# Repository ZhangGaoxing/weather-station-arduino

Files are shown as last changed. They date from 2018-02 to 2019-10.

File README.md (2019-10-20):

# Weather Station
## Introduction
This project includes an Arduino-based weather station, an ASP.NET Core MVC data presentation page, and an ASP.NET Core WebAPI. The collected data is sent using ESP8266 and written to the SQL Server database via WebAPI. The weather station consists of the following parts:

* Arduino Nano
* Nano Shield
* BME280 - Temperature, Humidity & Pressure Sensor
* ~~AM2320 - Digital Temperature and Humidity Sensor~~
* ~~BMP280 - Barometric Pressure and Altitude Sensor~~
* ~~ML8511 - UV sensor (Abandon)~~
* GP2Y1010F45 - Optical Dust Sensor
* DS3231 - RTC
* ESP8266 - WIFI
* SD card module
* 18650 Li-ion and Charger (Optional)

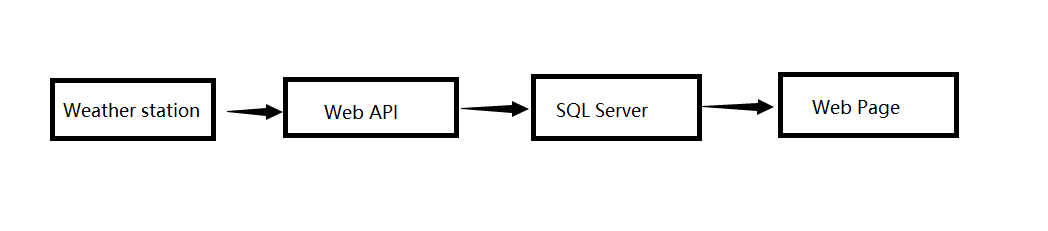
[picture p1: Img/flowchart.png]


Most of the referenced libraries come from Adafruit and Aduino Playground, and some I don't know who written it. AM2320 comes from [thakshak](https://github.com/thakshak/AM2320).

## Components
||Name|Count|
|---|:---|---:|
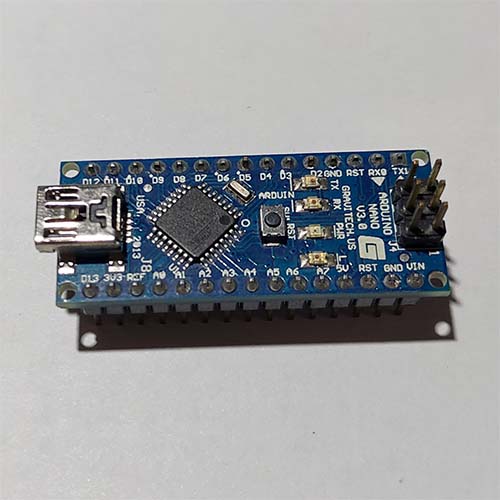
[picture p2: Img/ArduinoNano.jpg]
||Arduino Nano|x1|
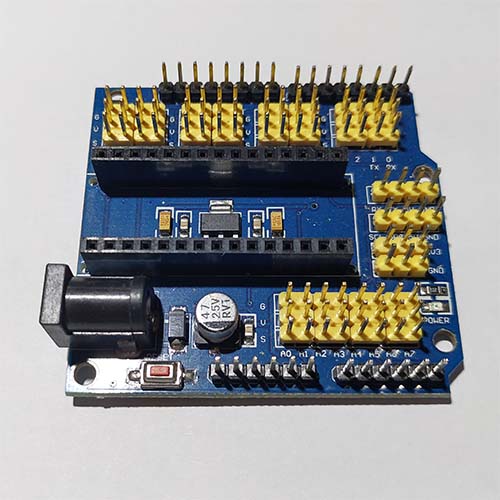
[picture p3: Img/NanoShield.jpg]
||Nano Shield|x1|
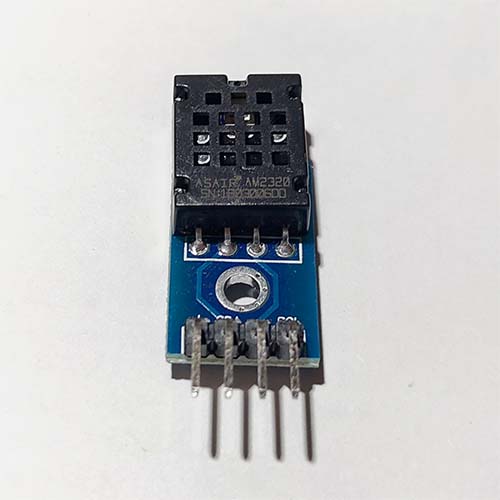
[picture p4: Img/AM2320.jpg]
||AM2320|x1|
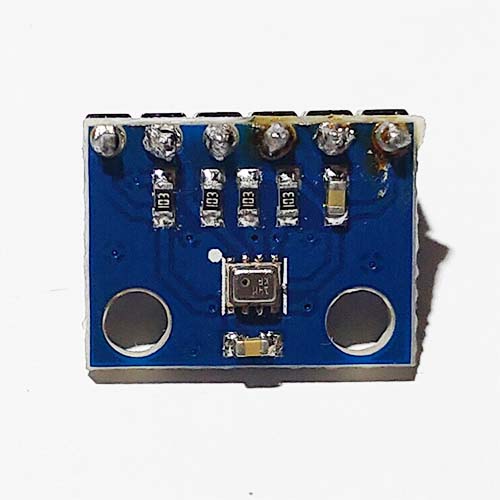
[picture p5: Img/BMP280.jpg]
||BMP280|x1|
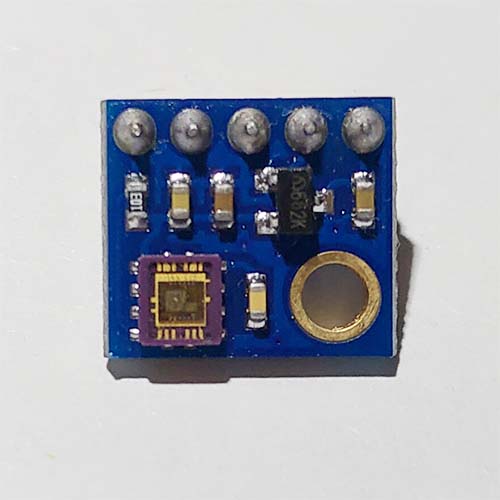
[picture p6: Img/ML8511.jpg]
||ML8511|x1|
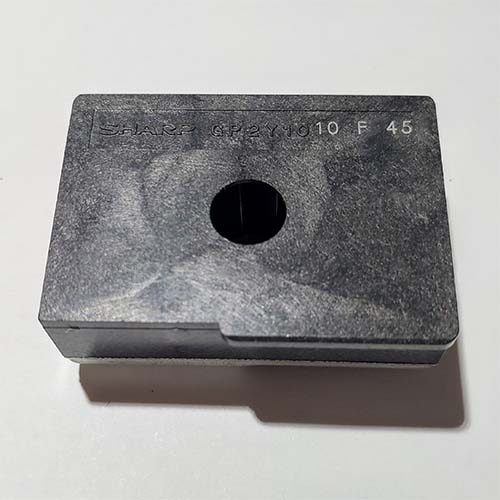
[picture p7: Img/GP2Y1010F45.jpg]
||GP2Y1010F45|x1|
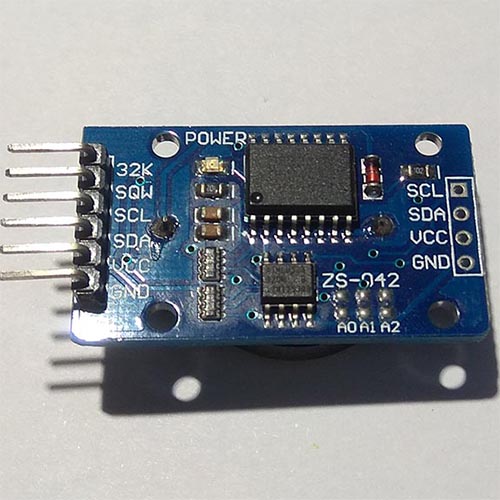
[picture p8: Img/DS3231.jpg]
||DS3231|x1|
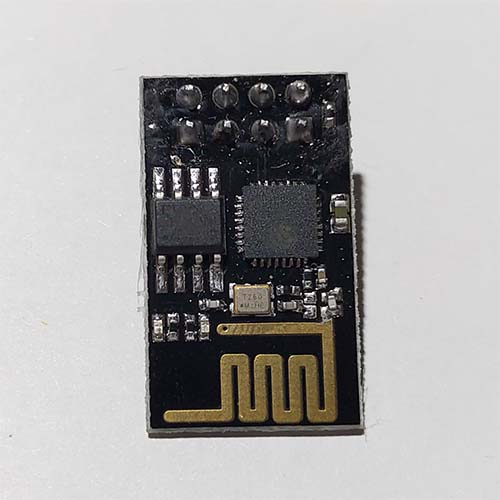
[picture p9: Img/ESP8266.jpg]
||ESP8266|x1|
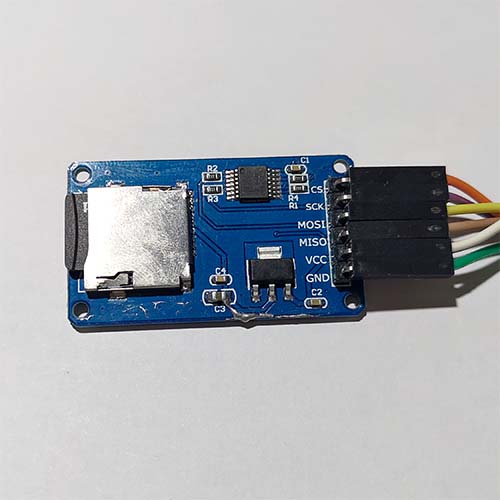
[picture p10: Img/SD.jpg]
||SD card module|x1|
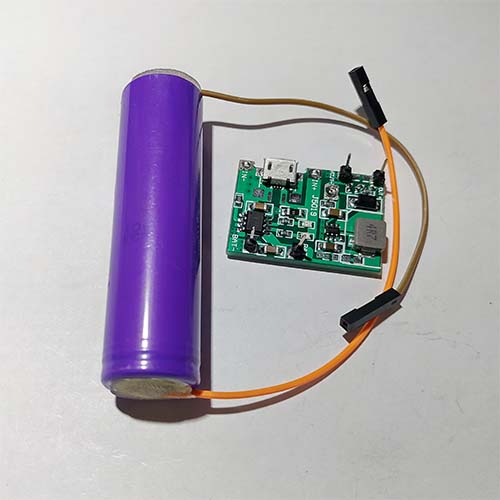
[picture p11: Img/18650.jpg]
||18650 Li-ion and Charger (Optional)|x1|
||Male/Female Jumper Wires|some|

## Apps
||Name|
|---|---|
||Arduino IDE|
||Microsoft Visual Studio 2017|
||Microsoft SQL Server|

## Arduino Connection
* I2C Sensors
  * VCC - 5V
  * GND - GND
  * SDA - A4
  * SCL - A5
  
* ML8511
  * VIN - 3.3V
  * OUT - A0
  * GND - GND
  * EN - 3.3V
  * 3.3V - A1

* GP2Y1010F45
  * Sharp pin 1 (V-LED) - 5V (Series 150Ω resistor, pin 1 and resistance connected to 220 μF capacitor and grounded)
  * Sharp pin 2 (LED-GND) - GND
  * Sharp pin 3 (LED) - pin 4
  * Sharp pin 4 (S-GND) - GND
  * Sharp pin 5 (Vo) - A2
  * Sharp pin 6 (Vcc) - 5V

* ESP8266
  * TX - pin 3
  * RX - pin 2
  * CH_PD - pin 5
  * VCC - 3.3V
  * GND - GND

* SD Card
  * MOSI - pin 11
  * MISO - pin 12
  * CLK - pin 13
  * CS - pin 10

## How to Use
Connect sensors to Arduino.

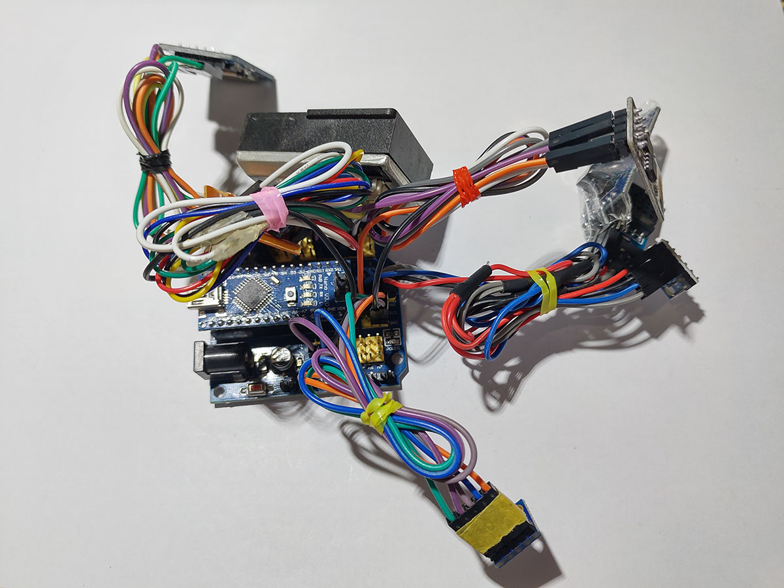
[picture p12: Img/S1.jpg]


### In ASP.NET Core
1. Open "**WeatherStation.sln**" and rebuild solution
   
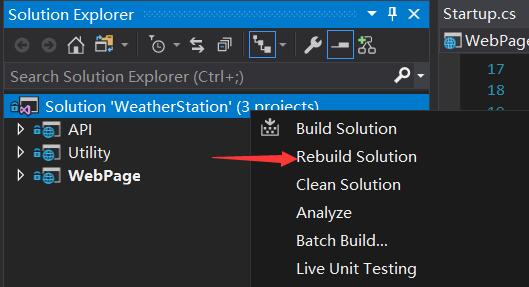
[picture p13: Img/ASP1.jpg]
    

2. In project **Utility**, open **WeatherContext.cs**, change connection string

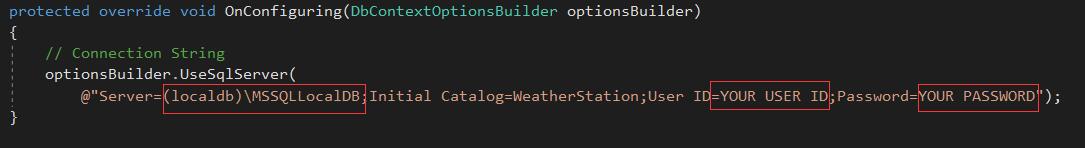
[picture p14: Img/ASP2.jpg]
    

3. In project **API**, open Controllers - **WeatherController.cs**, change token

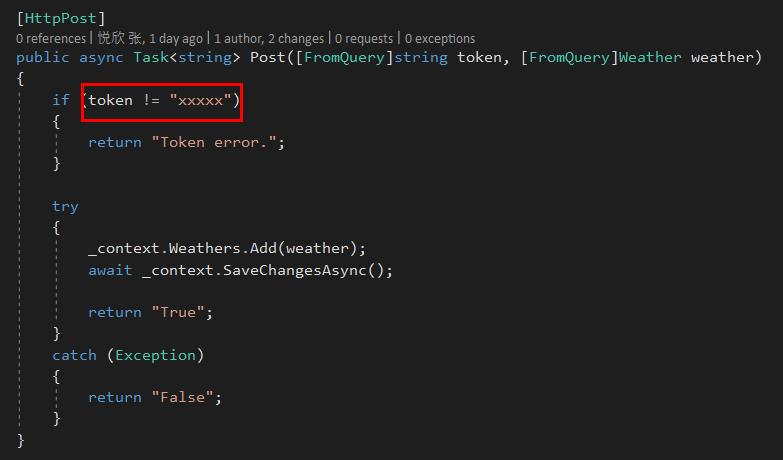
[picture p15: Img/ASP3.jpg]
    

4. Open Tools - NuGet Package Manager - **Package Manager Console**, change **Default project** to **Utility**
   
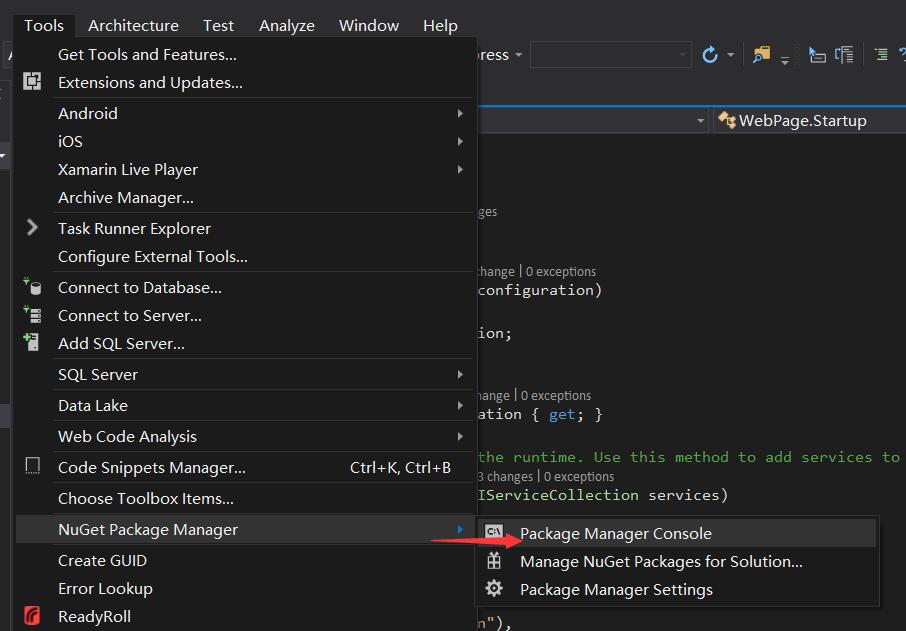
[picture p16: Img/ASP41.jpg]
    
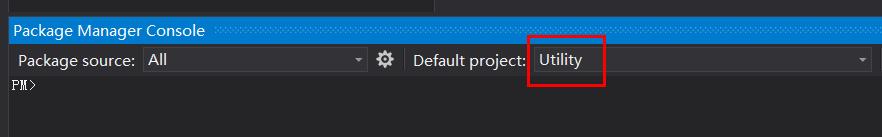
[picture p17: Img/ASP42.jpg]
    

    in PMC run this
    ```
    PM> Add-Migration Initial
    PM> Update-Database
    ```
    or run this SQL (PostgreSQL script)
    ```SQL
    create database "WeatherStation";

    create table weather (
        weather_id           SERIAL not null,
        date_time            TIMESTAMP            null,
        weather_name         VARCHAR(10)          null,
        temperature          NUMERIC(4,2)         null,
        humidity             NUMERIC(4,2)         null,
        pressure             NUMERIC(10,2)        null,
        dust                 NUMERIC(4)           null,
        uv                   DECIMAL(4,2)         null,
        constraint PK_WEATHER primary key (weather_id)
    );

    insert into "public"."weather" ("weather_id","date_time","weather_name","temperature","humidity","pressure","dust","uv") VALUES (1, '2019-01-01 21:00:00', NULL, -0.90, 25.80, 103662.72, 0, 0.01),(2, '2019-01-01 22:00:00', NULL, -1.50, 28.80, 103729.69, 0, 0.01),(3, '2019-01-01 23:00:00', NULL, -2.20, 29.60, 103632.05, 0, 0.01),(4, '2019-01-02 00:00:00', NULL, -2.90, 31.80, 103884.52, 0, 0.01),(5, '2019-01-02 01:00:00', NULL, -3.60, 33.80, 103603.38, 0, 0.01),(6, '2019-01-02 02:00:00', NULL, -3.50, 32.80, 103704.99, 0, 0.01),(7, '2019-01-02 03:00:00', NULL, -3.10, 31.20, 103872.41, 0, 0.01),(8, '2019-01-02 04:00:00', NULL, -2.70, 29.20, 103882.69, 0, 0.01);
    ```

5. Publish **API**, **WebPage** to your server

### In Arduino
1. Copy libraries to **x:\Program Files (x86)\Arduino\libraries**
2. Open "**WeatherStation.ino**"
3. In **Line 134**, replace your WIFI name and password
4. In **Line 139**, replace your server address and port
5. In **Line 150**, replace your Token
6. In **Line 155**, replace your Host

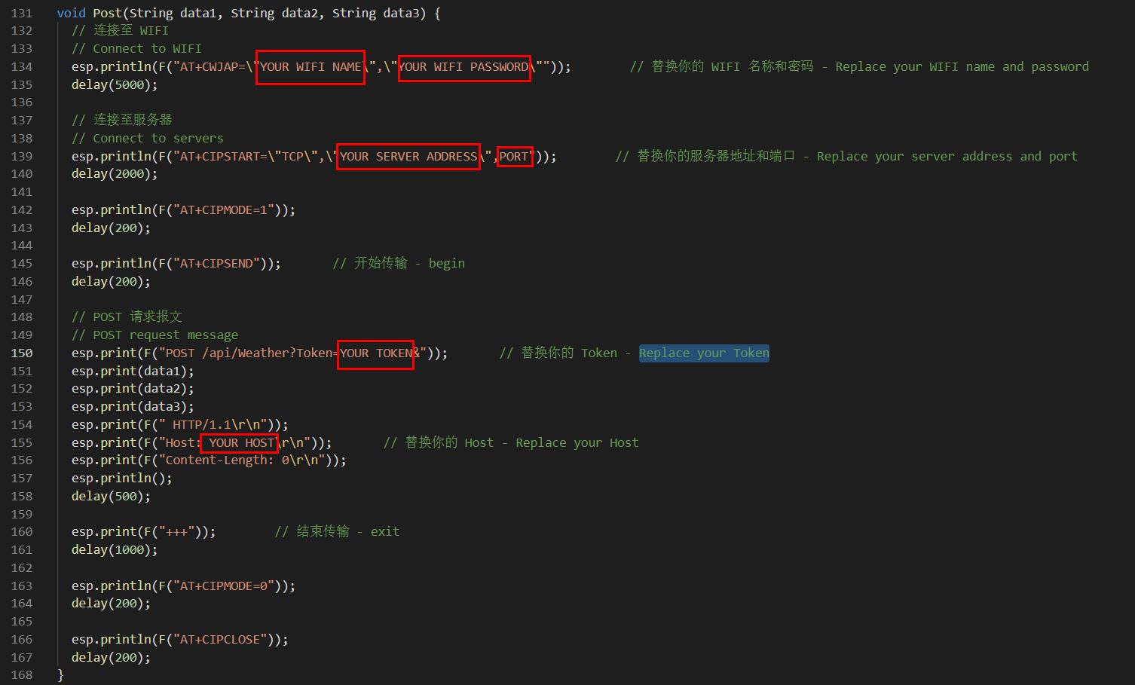
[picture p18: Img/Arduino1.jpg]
    

7. Upload program to your Arduino

## Demo Page
[http://weatherstation.zhangyue.xin/](http://weatherstation.zhangyue.xin)

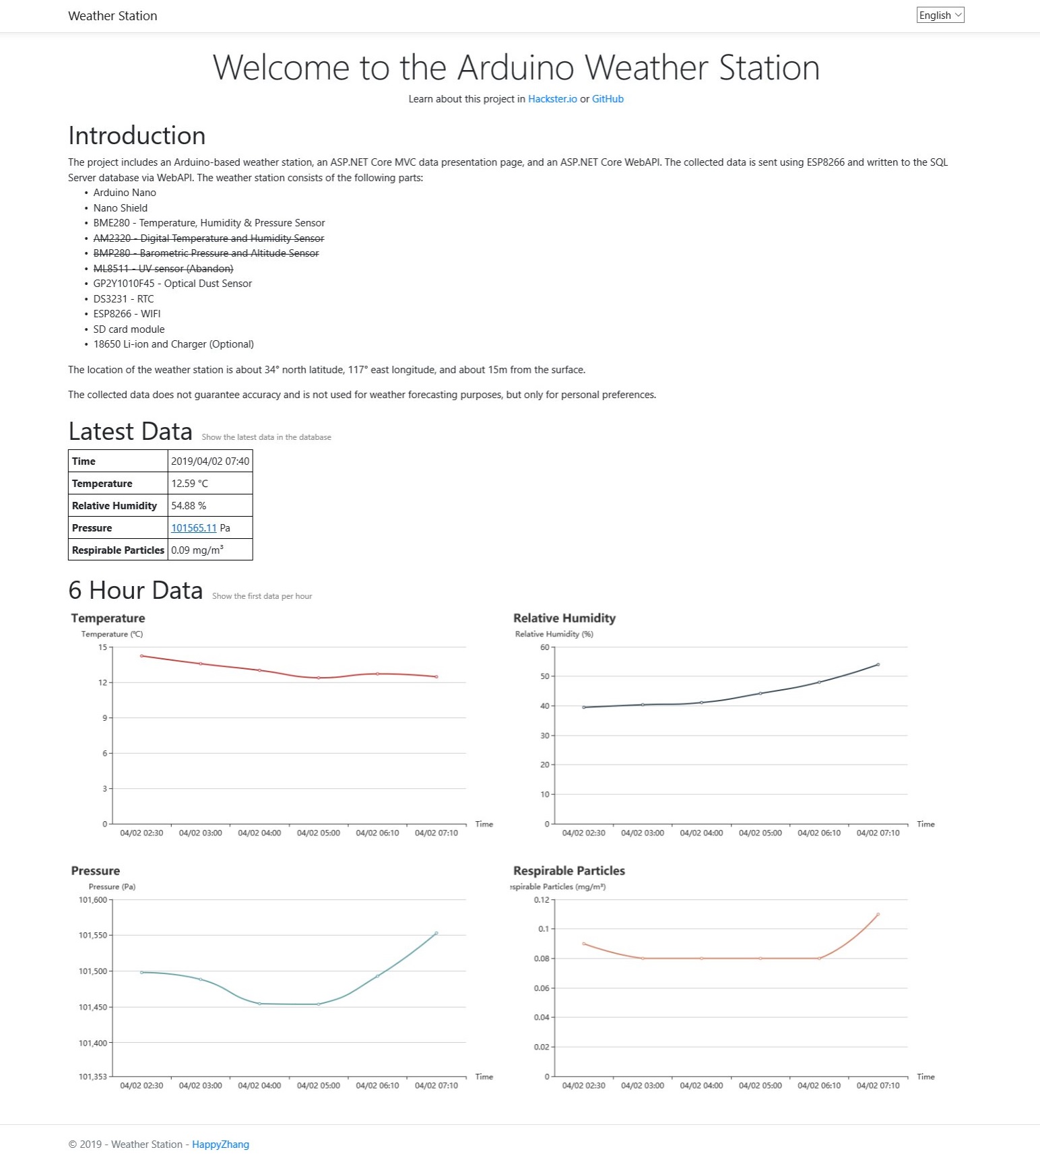
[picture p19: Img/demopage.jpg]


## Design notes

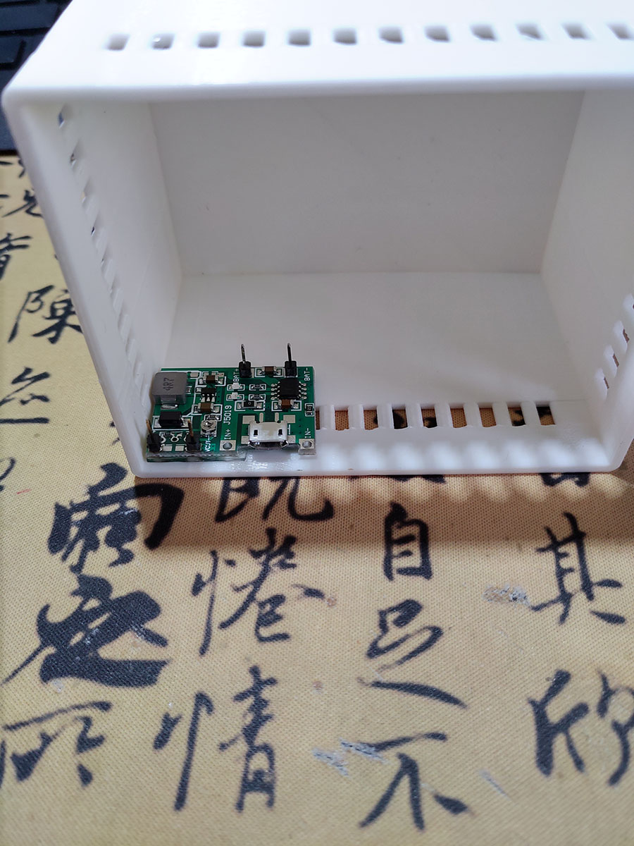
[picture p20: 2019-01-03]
Img/S2.jpg

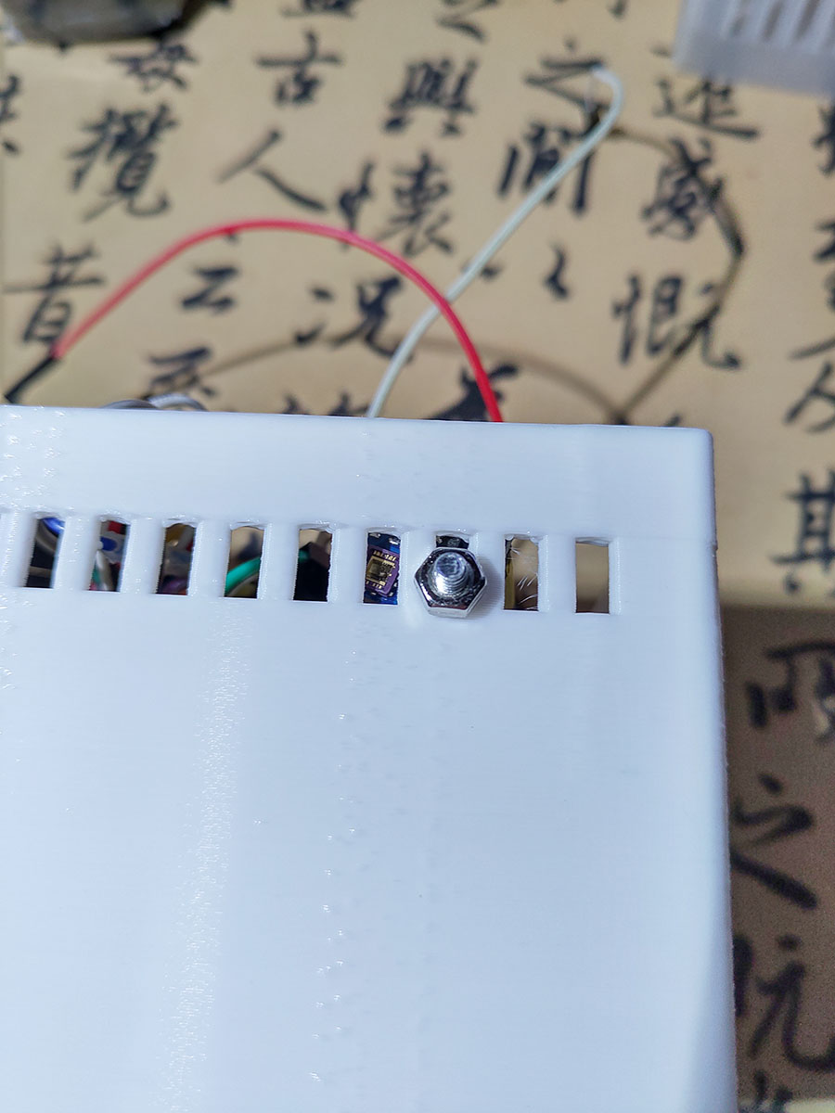
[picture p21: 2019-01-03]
Img/S4.jpg

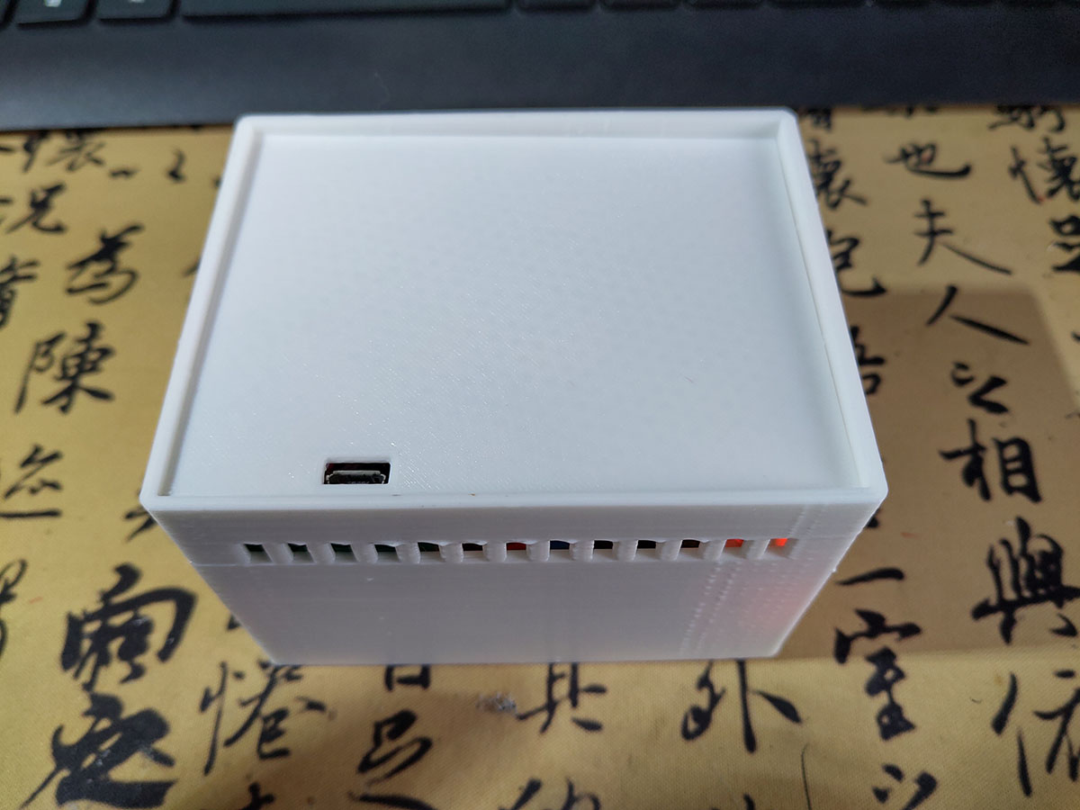
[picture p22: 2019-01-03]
Img/S5.jpg

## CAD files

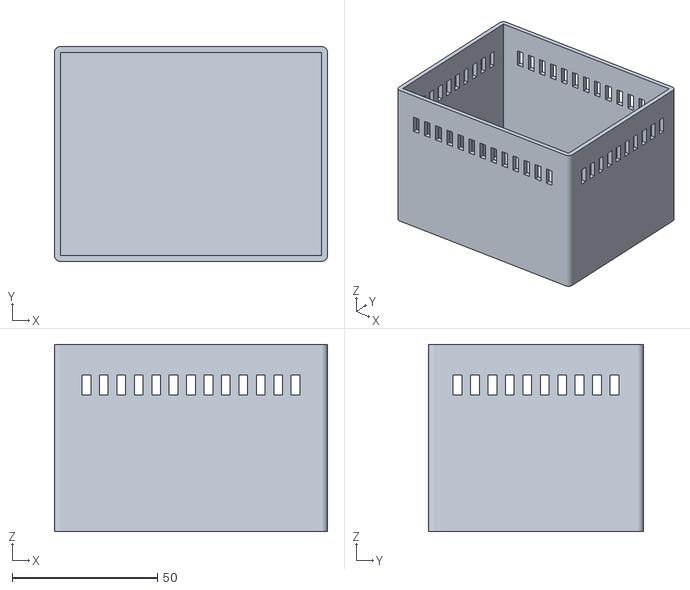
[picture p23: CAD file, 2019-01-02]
Arduino/WeatherStation/case_bottom.stl
94.0 x 74.0 x 64.5

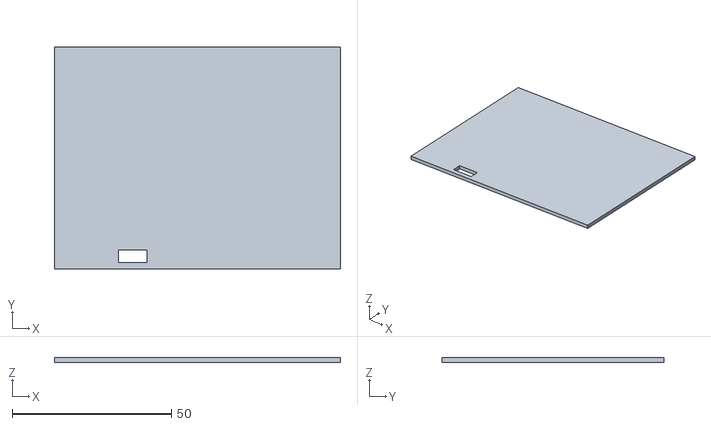
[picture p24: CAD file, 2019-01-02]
Arduino/WeatherStation/case_top.stl
89.7 x 69.7 x 1.50

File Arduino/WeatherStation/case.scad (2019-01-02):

$fn=200;

case1();

module case2(){
    difference(){
        cube([89.7,69.7,1.5]);
        
        translate([20,2,0])cube([9,4,1.5]);
    }
}

module case1(){
    difference(){
        minkowski()
        {
          cube([90,70,31.5]);
          cylinder(r=2,h=33);
        }
        
        translate([0,0,1.5])cube([90,70,66]);
        
        translate([7.5,-2.5,0])lines1();
        translate([7.5,69,0])lines1();
        
        translate([-2.5,6.5,0])lines2();
        translate([89,6.5,0])lines2();
    }
}

module lines1(){
    union(){
        translate([0,0,47])cube([3,5,7]);
        translate([6,0,47])cube([3,5,7]);
        translate([12,0,47])cube([3,5,7]);
        translate([18,0,47])cube([3,5,7]);
        translate([24,0,47])cube([3,5,7]);
        translate([30,0,47])cube([3,5,7]);
        translate([36,0,47])cube([3,5,7]);
        translate([42,0,47])cube([3,5,7]);
        translate([48,0,47])cube([3,5,7]);
        translate([54,0,47])cube([3,5,7]);
        translate([60,0,47])cube([3,5,7]);
        translate([66,0,47])cube([3,5,7]);
        translate([72,0,47])cube([3,5,7]);
    }
}

module lines2(){
    union(){
        translate([0,0,47])cube([5,3,7]);
        translate([0,6,47])cube([5,3,7]);
        translate([0,12,47])cube([5,3,7]);
        translate([0,18,47])cube([5,3,7]);
        translate([0,24,47])cube([5,3,7]);
        translate([0,30,47])cube([5,3,7]);
        translate([0,36,47])cube([5,3,7]);
        translate([0,42,47])cube([5,3,7]);
        translate([0,48,47])cube([5,3,7]);
        translate([0,54,47])cube([5,3,7]);
    }
    
}

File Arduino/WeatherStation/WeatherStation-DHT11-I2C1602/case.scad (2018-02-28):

$fn=50;

case1();

module case2(){
    difference(){
        cube([89.7,69.7,1.5]);
    
        translate([4,23,0])union(){
            translate([7,0,0])cube([71,24,1.5]);
            cube([7,7,1.5]);
            translate([64.5,24,0])cube([3.5,4.5,1.5]);
        }
    }
}

module case1(){
    difference(){
        minkowski()
        {
          cube([90,70,31.5]);
          cylinder(r=1.5,h=31.5);
        }
        
        translate([0,0,1.5])cube([90,70,63]);
        
        translate([7.5,-2.5,0])lines1();
        translate([7.5,69,0])lines1();
        
        translate([-2.5,6.5,0])lines2();
        translate([89,6.5,0])lines2();
    }
}

module lines1(){
    union(){
        translate([0,0,10.5])cube([3,5,42]);
        translate([6,0,10.5])cube([3,5,42]);
        translate([12,0,10.5])cube([3,5,42]);
        translate([18,0,10.5])cube([3,5,42]);
        translate([24,0,10.5])cube([3,5,42]);
        translate([30,0,10.5])cube([3,5,42]);
        translate([36,0,10.5])cube([3,5,42]);
        translate([42,0,10.5])cube([3,5,42]);
        translate([48,0,10.5])cube([3,5,42]);
        translate([54,0,10.5])cube([3,5,42]);
        translate([60,0,10.5])cube([3,5,42]);
        translate([66,0,10.5])cube([3,5,42]);
        translate([72,0,10.5])cube([3,5,42]);
    }
}

module lines2(){
    union(){
        translate([0,0,10.5])cube([5,3,42]);
        translate([0,6,10.5])cube([5,3,42]);
        translate([0,12,10.5])cube([5,3,42]);
        translate([0,18,10.5])cube([5,3,42]);
        translate([0,24,10.5])cube([5,3,42]);
        translate([0,30,10.5])cube([5,3,42]);
        translate([0,36,10.5])cube([5,3,42]);
        translate([0,42,10.5])cube([5,3,42]);
        translate([0,48,10.5])cube([5,3,42]);
        translate([0,54,10.5])cube([5,3,42]);
    }
    
}

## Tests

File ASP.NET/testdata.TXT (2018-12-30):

2018/12/29 20:40:31,1.30,19.60,103603.88,0.14,0.05
2018/12/29 20:50:31,-0.30,24.40,103656.42,0.14,0.04
2018/12/29 21:00:30,-0.90,25.80,103662.72,0.14,0.07
2018/12/29 21:10:30,-0.90,25.80,103626.75,0.14,0.07
2018/12/29 21:20:29,-1.00,26.20,103648.30,0.14,0.06
2018/12/29 21:30:29,-1.00,27.60,103661.07,0.14,0.05
2018/12/29 21:40:29,-1.00,27.80,103692.22,0.14,0.05
2018/12/29 21:50:28,-1.20,28.00,103703.00,0.14,0.06
2018/12/29 22:00:28,-1.50,28.30,103729.69,0.14,0.06
2018/12/29 22:10:28,-1.50,28.60,103743.61,0.14,0.06
2018/12/29 22:20:27,-1.50,29.00,103678.64,0.14,0.05
2018/12/29 22:30:27,-1.50,29.30,103623.10,0.14,0.04
2018/12/29 22:40:26,-1.40,29.60,103632.05,0.14,0.05
2018/12/29 22:50:26,-1.10,28.40,103621.11,0.14,0.07
2018/12/29 23:00:26,-1.00,28.30,103624.43,0.14,0.06
2018/12/29 23:10:25,-0.90,27.30,103715.77,0.14,0.06
2018/12/29 23:20:25,-1.10,27.40,103647.30,0.15,0.06
2018/12/29 23:30:24,-0.90,27.40,103739.64,0.14,0.06
2018/12/29 23:40:24,-1.20,27.40,103777.76,0.14,0.06
2018/12/29 23:50:24,-1.50,27.60,103771.79,0.14,0.06
2018/12/30 00:00:23,-1.60,27.80,103823.51,0.14,0.06
2018/12/30 00:10:23,-1.60,28.10,103884.52,0.15,0.05
2018/12/30 00:20:22,-2.00,28.50,103838.42,0.15,0.07
2018/12/30 00:30:22,-1.90,28.80,103825.17,0.15,0.06
2018/12/30 00:40:22,-2.00,29.20,103759.69,0.15,0.07
2018/12/30 00:50:21,-1.90,29.60,103787.05,0.14,0.06
2018/12/30 01:00:21,-1.80,29.70,103784.06,0.15,0.06
2018/12/30 01:10:20,-1.90,29.90,103713.77,0.15,0.06
2018/12/30 01:20:20,-1.60,30.00,103665.04,0.15,0.06
2018/12/30 01:30:20,-1.40,29.60,103603.38,0.14,0.05
2018/12/30 01:40:19,-1.00,29.60,103653.94,0.14,0.08
2018/12/30 01:50:19,-1.00,29.60,103662.06,0.14,0.06
2018/12/30 02:00:18,-1.20,29.70,103725.71,0.14,0.06
2018/12/30 02:10:18,-1.70,30.00,103704.99,0.14,0.06
2018/12/30 02:20:18,-1.70,30.70,103788.03,0.15,0.07
2018/12/30 02:30:17,-2.00,31.70,103910.53,0.15,0.05
2018/12/30 02:40:17,-2.40,32.20,103910.21,0.14,0.06
2018/12/30 02:50:16,-2.50,33.10,103879.21,0.15,0.06
2018/12/30 03:00:16,-2.60,34.00,103956.29,0.15,0.06
2018/12/30 03:10:16,-2.70,34.30,103879.54,0.15,0.07
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

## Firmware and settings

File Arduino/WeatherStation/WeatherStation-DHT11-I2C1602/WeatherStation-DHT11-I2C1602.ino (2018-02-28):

/***************************
 * SD Card
 * MOSI - pin 11
 * MISO - pin 12
 * CLK - pin 13
 * CS - pin 10
 *
 * UV Sensor
 * VIN - 3.3V
 * OUT - A0
 * GND - GND
 * EN - 3.3V
 * 3.3V - A1
 * 
 * Dust Sensor
 * Sharp pin 1 (V-LED) - 5V (串联150Ω电阻，pin 1和电阻之间连220μF电容接地)
 * Sharp pin 2 (LED-GND) - GND
 * Sharp pin 3 (LED) - pin 2 
 * Sharp pin 4 (S-GND) - GND
 * Sharp pin 5 (Vo) - A0
 * Sharp pin 6 (Vcc) - 5V
 * 
 * I2C Sensors
 * VCC - 5V
 * GND - GND
 * SDA - A4
 * SCL - A5
 * 
 * DHT11
 * OUT - PIN 2
 * VCC - 5V
 * GND - GND
 **************************/

#include <DS3231.h>
#include <Adafruit_BMP280.h>
#include <dht11.h>
#include <LiquidCrystal_I2C.h>
#include <Wire.h>
#include <SPI.h>
#include <SD.h>
const int chipSelect = 10;

byte deg[8] = {
  B11000,
  B11000,
  B00111,
  B01000,
  B01000,
  B01000,
  B00111,
  B00000
};
byte three[8]={
  B11100,
  B00010,
  B01100,
  B00010,
  B11100,
  B00000,
  B00000,
  B00000
};
byte two[8] = {
  B01100,
  B10010,
  B00100,
  B01000,
  B11110,
  B00000,
  B00000,
  B00000
};
byte b4[8] = {
  B01110,
  B11111,
  B11111,
  B11111,
  B11111,
  B11111,
  B11111,
  B00000
};
byte b3[8] = {
  B01110,
  B11111,
  B10001,
  B11111,
  B11111,
  B11111,
  B11111,
  B00000
};
byte b2[8] = {
  B01110,
  B11111,
  B10001,
  B10001,
  B11111,
  B11111,
  B11111,
  B00000
};
byte b1[8] = {
  B01110,
  B11111,
  B10001,
  B10001,
  B10001,
  B11111,
  B11111,
  B00000
};
byte b0[8] = {
  B01110,
  B11111,
  B10001,
  B10001,
  B10001,
  B10001,
  B11111,
  B00000
};

dht11 DHT11;
const int DHT_PIN = 2;
DS3231 Clock;
Adafruit_BMP280 bmp;
LiquidCrystal_I2C lcd(0x3F,16,2);
const int LCD_SWITCH_PIN=3;
const int UV_OUT = A0;
const int UV_3V3 = A1;
const int BAT_PIN=A7;

const int DUST_SAMPLING_TIME = 280; 
const int DUST_DELTA_TIME = 40; 
const int DUST_SLEEP_TIME = 9680; 
const int DUST_LED_PIN=4;
const int DUST_OUT_PIN=A2;

const unsigned long INTERVAL=120000;
unsigned long last=0;
unsigned long now=0;
unsigned long minus=0;

void setup() {
  Serial.begin(9600);
  Wire.begin();
  //LCD Initialize
  lcd.init();
  lcd.noDisplay();
  lcd.createChar(0, deg); 
  lcd.createChar(1, two); 
  lcd.createChar(5, three);
  lcd.createChar(2, b4); 
  lcd.createChar(3, b2); 
  lcd.createChar(4, b0); 
  //LCD Switch Initialize
  pinMode(LCD_SWITCH_PIN, INPUT_PULLUP);
  //BMP280 Initialize
  bmp.begin();
  //UV Initialize
  pinMode(UV_OUT, INPUT);
  pinMode(UV_3V3, INPUT);
  //
  pinMode(DUST_LED_PIN,OUTPUT);
  //SD Initialize
  if (SD.begin(chipSelect))
  {
    Serial.println("SD initialize done.");
    if (!SD.exists("datalog.txt")) {
      File dataFile = SD.open("datalog.txt", FILE_WRITE);
      dataFile.println("Time,Temperature(℃),Humidity(%),Pressure(Pa),UV(mW/cm^2),Dust(mg/m3)");
      dataFile.close();
    }
    WriteSD();
  }
}

void loop() {
 /* Serial.println(ReadTime());
  Serial.println(ReadDHT11());
  Serial.println(ReadBMP());
  Serial.println(ReadUV());
  Serial.println();
  WriteSD();
  delay(1000);
  Display();
  delay(1000);*/
  //Detect LCD switch press
  if(digitalRead(LCD_SWITCH_PIN)==LOW){
    lcd.backlight();
    lcd.display();
    Display();
    Display();
    lcd.noBacklight();
    lcd.noDisplay();
  }

  now=millis();
  minus=now-last;
  if(minus>INTERVAL){
    last=now;
    WriteSD();
  }
}

int ReadBattery(){
  int val=analogRead(BAT_PIN);
  float volts=(val/1023.0)*5;
  int per=(volts-3.2)*100;
  int res=4;
  if(per>=60){
    res=2;
  }
  else if(per>=20&&per<60){
    res=3;
  }
  else{
    res=4;
  }
  return res;
}

void Display(){
  bool h12,PM,Century;
  int second=0,minute=0,hour=0,date=0,month=0,year=0; 
  String secondDis="",minuteDis="",hourDis="",dateDis="",monthDis="";
  int dustLevel=0;
  float temp=0,press=0,hum=0,dust=0,dustRaw=0;
  String tempDis="",pressDis="",humDis="",uvDis="",dustLevelDis="",timeDis="",resDis="";

  //read time
  second=Clock.getSecond();
  minute=Clock.getMinute();
  hour=Clock.getHour(h12, PM);
  date=Clock.getDate();
  month=Clock.getMonth(Century);
  year=Clock.getYear();

  if(second<10)
    secondDis=secondDis+"0"+second;
  else
    secondDis+=second;
  if(minute<10)
    minuteDis=minuteDis+"0"+minute;
  else
    minuteDis+=minute;
  if(hour<10)
    hourDis=hourDis+"0"+hour;
  else
    hourDis+=hour;
  if(date<10)
    dateDis=dateDis+"0"+date;
  else
    dateDis+=date;
  if(month<10)
    monthDis=monthDis+"0"+month;
  else
    monthDis+=month;
  timeDis=timeDis+year+"/"+monthDis+"/"+dateDis+" "+hourDis+":"+minuteDis;//+":"+secondDis;

  //read bmp280
  temp=bmp.readTemperature();
  press=bmp.readPressure();

  tempDis=tempDis+"Temp:"+temp;
  pressDis=pressDis+"Pres:"+press+"Pa";
  
  //print in LCD
  lcd.clear();
  lcd.setCursor(0,0);
  lcd.print(timeDis);
  lcd.setCursor(15,0);
  lcd.write(ReadBattery());
  lcd.setCursor(0,1);
  lcd.print(tempDis);
  lcd.write(0);
  delay(5000);

  //read dht11
  int chk = DHT11.read(DHT_PIN);
  switch (chk)
  {
    case DHTLIB_OK: 
      hum=DHT11.humidity;
      break;
    default: 
      hum=0; 
      break;
  }
  humDis=humDis+"Humi:"+hum+"%";
  
  lcd.clear();
  lcd.setCursor(0,0);
  lcd.print(humDis);
  lcd.setCursor(0,1);
  lcd.print(pressDis);
  delay(5000);

  //read uv
  int uvLevel = averageAnalogRead(UV_OUT);
  int refLevel = averageAnalogRead(UV_3V3);
  float outputVoltage = 3.3 / refLevel * uvLevel;
  float uvIntensity = mapfloat(outputVoltage, 0.99, 2.9, 0.0, 15.0);

  lcd.clear();
  lcd.setCursor(0,0);
  lcd.print("UV(mW/cm");
  lcd.write(1);
  lcd.print("):");
  lcd.print(uvIntensity);
  lcd.setCursor(0,1);
  lcd.print("Level:");
  lcd.print((int)(uvIntensity*10*0.04));
  delay(5000);

  //read sharp
  dustRaw=ReadDust();
  dustLevel=((dustRaw/1024.0)-0.0356)*120000*0.035;
  if(dustLevel>=3000){
    dustLevelDis="Very Bad";
  }
  else if(dustLevel>=1050&&dustLevel<3000){
    dustLevelDis="Bad";
  }
  else if(dustLevel>=300&&dustLevel<1050){
    dustLevelDis="Medium";
  }
  else if(dustLevel>=150&&dustLevel<300){
    dustLevelDis="Good";
  }
  else if(dustLevel>=75&&dustLevel<150){
    dustLevelDis="Very Good";
  }
  else if(dustLevel>=0&&dustLevel<75){
    dustLevelDis="Perfect";
  }
  else{
    dustLevelDis="Error";
  }
  float calcVoltage = dustRaw * (5.0 / 1024.0);
  dust = 0.17 * calcVoltage - 0.1;
  
  lcd.clear();
  lcd.setCursor(0,0);
  lcd.print("Dust(mg/m");
  lcd.write(5);
  lcd.print("):");
  lcd.print(dust);
  lcd.setCursor(0,1);
  lcd.print("Level:");
  lcd.print(dustLevelDis);
  delay(5000);
}

void WriteSD(){
  File dataFile = SD.open("datalog.txt", FILE_WRITE);
  dataFile.print(ReadTime());
  dataFile.print(",");
  dataFile.print(bmp.readTemperature());
  dataFile.print(",");
  DHT11.read(DHT_PIN);
  dataFile.print(DHT11.humidity);
  dataFile.print(",");
  dataFile.print(bmp.readPressure());
  dataFile.print(",");
  int uvLevel = averageAnalogRead(UV_OUT);
  int refLevel = averageAnalogRead(UV_3V3);
  float outputVoltage = 3.3 / refLevel * uvLevel;
  float uvIntensity = mapfloat(outputVoltage, 0.99, 2.9, 0.0, 15.0);
  dataFile.print(uvIntensity);
  dataFile.print(",");
  dataFile.println(ReadDustForSD());
  dataFile.close();
}

/***************************************
 * Method for Serial.print()
****************************************/
float ReadDust(){
  float voMeasured = 0; //Raw Signal Value (0-1023)
  //float calcVoltage = 0; //Voltage
  //float dustDensity = 0;
  
  digitalWrite(DUST_LED_PIN,LOW); // power on the LED
  delayMicroseconds(DUST_SAMPLING_TIME);

  voMeasured = analogRead(DUST_OUT_PIN); // read the dust value

  delayMicroseconds(DUST_DELTA_TIME);
  digitalWrite(DUST_LED_PIN,HIGH); // turn the LED off
  delayMicroseconds(DUST_SLEEP_TIME);

  // 0 - 5V mapped to 0 - 1023 integer values
  // recover voltage
  //calcVoltage = (float)voMeasured * (5.0 / 1024.0);

  // linear eqaution taken from http://www.howmuchsnow.com/arduino/airquality/
  // Chris Nafis (c) 2012
  //level=((voMeasured/1024)-0.0356)*120000*0.035
  //dustDensity = 0.17 * calcVoltage - 0.1;
  /*if ( calcVoltage >= 0.6 )
  {
      dustDensity = 0.17 * calcVoltage - 0.1;
  }
  else
  {
      dustDensity = 0;
  }*/

  return voMeasured;
} 

float ReadDustForSD(){
  float voMeasured = 0; //Raw Signal Value (0-1023)
  float calcVoltage = 0; //Voltage
  float dustDensity = 0;
  
  digitalWrite(DUST_LED_PIN,LOW); // power on the LED
  delayMicroseconds(DUST_SAMPLING_TIME);

  voMeasured = analogRead(DUST_OUT_PIN); // read the dust value

  delayMicroseconds(DUST_DELTA_TIME);
  digitalWrite(DUST_LED_PIN,HIGH); // turn the LED off
  delayMicroseconds(DUST_SLEEP_TIME);

  // 0 - 5V mapped to 0 - 1023 integer values
  // recover voltage
  calcVoltage = (float)voMeasured * (5.0 / 1024.0);

  // linear eqaution taken from http://www.howmuchsnow.com/arduino/airquality/
  // Chris Nafis (c) 2012
  //level=((voMeasured/1024)-0.0356)*120000*0.035
  //dustDensity = 0.17 * calcVoltage - 0.1;
  if ( calcVoltage >= 0.6 )
  {
      dustDensity = 0.17 * calcVoltage - 0.1;
  }
  else
  {
      dustDensity = 0;
  }

  return dustDensity;
} 

String ReadTime(){
  String time="";
  bool h12,PM,Century;
  int second=0,minute=0,hour=0,date=0,month=0,year=0; 
  String secondStr="",minuteStr="",hourStr="",dateStr="",monthStr="";
  
  second=Clock.getSecond();
  minute=Clock.getMinute();
  hour=Clock.getHour(h12, PM);
  date=Clock.getDate();
  month=Clock.getMonth(Century);
  year=Clock.getYear();

  if(second<10)
    secondStr=secondStr+"0"+second;
  else
    secondStr+=second;
  if(minute<10)
    minuteStr=minuteStr+"0"+minute;
  else
    minuteStr+=minute;
  if(hour<10)
    hourStr=hourStr+"0"+hour;
  else
    hourStr+=hour;
  if(date<10)
    dateStr=dateStr+"0"+date;
  else
    dateStr+=date;
  if(month<10)
    monthStr=monthStr+"0"+month;
  else
    monthStr+=month;
    
  time=time+"20"+year+"/"+monthStr+"/"+dateStr+" "+hourStr+":"+minuteStr+":"+secondStr;

  return time;
}

String ReadBMP(){
  String res="";
  float temp=0,press=0,alt=0;

  temp=bmp.readTemperature();
  press=bmp.readPressure();
  
  res=res+"Temperature:"+temp+"℃"+"  Pressure:"+press+"Pa";

  return res;
}

String ReadDHT11(){
  String res="";
  int chk = DHT11.read(DHT_PIN);
  switch (chk)
  {
    case DHTLIB_OK: 
      break;
    case DHTLIB_ERROR_CHECKSUM: 
      return "Checksum error"; 
    case DHTLIB_ERROR_TIMEOUT: 
      return "Time out error"; 
    default: 
      return "Unknown error"; 
  }

  res=res+"Humidity:"+DHT11.humidity+"%  Temperature:"+DHT11.temperature+"℃";

  return res;
}

String ReadUV(){
  String res="";
  int uvLevel = averageAnalogRead(UV_OUT);
  int refLevel = averageAnalogRead(UV_3V3);
  float outputVoltage = 3.3 / refLevel * uvLevel;
  float uvIntensity = mapfloat(outputVoltage, 0.99, 2.9, 0.0, 15.0);

  res=res+"UV Intensity (mW/cm^2):"+uvIntensity;

  return res;
}

int averageAnalogRead(int pinToRead)
{
  byte numberOfReadings = 8;
  unsigned int runningValue = 0; 

  for(int x = 0 ; x < numberOfReadings ; x++)
    runningValue += analogRead(pinToRead);
  runningValue /= numberOfReadings;

  return(runningValue);  
}

float mapfloat(float x, float in_min, float in_max, float out_min, float out_max)
{
  return (x - in_min) * (out_max - out_min) / (in_max - in_min) + out_min;
}

/*#define NOP do { __asm__ __volatile__ ("nop"); } while (0)
void _delay(int ms)
{
  for(int i=0; i<ms; i++){
    for(unsigned long j=0;j<1985;j++) NOP;
  }
}*/

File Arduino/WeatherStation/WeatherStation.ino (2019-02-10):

/***************************
SD Card
  MOSI - pin 11
  MISO - pin 12
  CLK - pin 13
  CS - pin 10

UV Sensor
  VIN - 3.3V
  OUT - A0
  GND - GND
  EN - 3.3V
  3.3V - A1

Dust Sensor
  Sharp pin 1 (V-LED) - 5V (串联150Ω电阻，pin 1和电阻之间连220μF电容接地)
  Sharp pin 2 (LED-GND) - GND
  Sharp pin 3 (LED) - pin 4
  Sharp pin 4 (S-GND) - GND
  Sharp pin 5 (Vo) - A2
  Sharp pin 6 (Vcc) - 5V

ESP8266
  TX - pin 3
  RX - pin 2
  CH_PD - pin 5
  VCC - 3.3V
  GND - GND

I2C Sensors
  VCC - 5V
  GND - GND
  SDA - A4
  SCL - A5
**************************/

#include <avr/pgmspace.h>
#include <SoftwareSerial.h>
#include <DS3231.h>
#include <Adafruit_BMP280.h>
#include <AM2320.h>
#include <SD.h>

const int SD_CS = 10;

DS3231 Clock;
AM2320 th;
Adafruit_BMP280 bmp;

const int UV_OUT = A0;
const int UV_3V3 = A1;

const int DUST_LED_PIN = 4;
const int DUST_OUT_PIN = A2;
const int DUST_SAMPLING_TIME = 280;
const int DUST_DELTA_TIME = 40;
const int DUST_SLEEP_TIME = 9680;

SoftwareSerial esp(3, 2);
const int CH_PD_PIN = 5;

bool Century=false;

void setup() {
  //BMP280 Initialize
  bmp.begin();

  //UV Initialize
  pinMode(UV_OUT, INPUT);
  pinMode(UV_3V3, INPUT);

  //Dust Initialize
  pinMode(DUST_LED_PIN, OUTPUT);

  //ESP8266 Initialize
  EspInit();

  //SD Initialize
  if (SD.begin(SD_CS))
  {
    WriteSdAndPost();
  }
}

void loop() {
  // 10 分钟传送一次数据
  // The interval of data transmission is 10 minutes
  int minute=Clock.getMinute();
  if(minute % 10 == 0)
    WriteSdAndPost();
  delay(60000);
}

void WriteSdAndPost() {
  // Time,Temperature(℃),Humidity(%),Pressure(Pa),UV(mW/cm2),Dust(mg/m3)
  bool Century;
  String fileName=(String)Clock.getYear()+"_"+Clock.getMonth(Century)+"_"+Clock.getDate()+".txt";

  File dataFile = SD.open(fileName, FILE_WRITE);
  String datetime = ReadTime();
  dataFile.print(datetime);
  dataFile.print(",");

  th.Read();
  dataFile.print(th.t);
  dataFile.print(",");
  dataFile.print(th.h);
  dataFile.print(",");

  float p = bmp.readPressure();
  dataFile.print(p);
  dataFile.print(",");

  float uv = ReadUV();
  dataFile.print(uv);
  dataFile.print(",");

  float dust = ReadDust();
  dataFile.println(dust);
  dataFile.close();

  // 单个字符串太长，拆分成3个
  // The string is too long, so I split it into 3.
  String data1 = (String)"DateTime=" + datetime;
  String data2 = (String)"&Temperature=" + th.t + "&Humidity=" + th.h;
  String data3 = (String)"&Pressure=" + p + "&Dust=" + dust + "&UV=" + uv;

  Post(data1, data2, data3);
}

void Post(String data1, String data2, String data3) {
  // 连接至 WIFI
  // Connect to WIFI
  esp.println(F("AT+CWJAP=\"YOUR WIFI NAME\",\"YOUR WIFI PASSWORD\""));        // 替换你的 WIFI 名称和密码 - Replace your WIFI name and password
  delay(5000);

  // 连接至服务器
  // Connect to servers
  esp.println(F("AT+CIPSTART=\"TCP\",\"YOUR SERVER ADDRESS\",PORT"));        // 替换你的服务器地址和端口 - Replace your server address and port
  delay(2000);
  
  esp.println(F("AT+CIPMODE=1"));
  delay(200);
  
  esp.println(F("AT+CIPSEND"));       // 开始传输 - begin
  delay(200);

  // POST 请求报文
  // POST request message
  esp.print(F("POST /api/Weather?Token=YOUR TOKEN&"));       // 替换你的 Token - Replace your Token
  esp.print(data1);
  esp.print(data2);
  esp.print(data3);
  esp.print(F(" HTTP/1.1\r\n"));
  esp.print(F("Host: YOUR HOST\r\n"));       // 替换你的 Host - Replace your Host
  esp.print(F("Content-Length: 0\r\n"));
  esp.println();
  delay(500);

  esp.print(F("+++"));        // 结束传输 - exit
  delay(1000);

  esp.println(F("AT+CIPMODE=0"));
  delay(200);
  
  esp.println(F("AT+CIPCLOSE"));
  delay(200);
}

void EspInit() {
  // 设置 CH_PD_PIN 为高电平
  // Set CH_PD_PIN to high level
  pinMode(CH_PD_PIN, OUTPUT);
  digitalWrite(CH_PD_PIN, HIGH);
  delay(1000);

  // 初始化软串口
  // SoftwareSerial init
  esp.begin(9600);
  delay(200);

  // 重启 ESP8266
  // Reboot ESP8266
  esp.println(F("AT+RST"));
  delay(5000);

  // STA 模式
  esp.println(F("AT+CWMODE=1"));
  delay(2000);

  esp.println(F("AT+CIPMUX=0"));
  delay(200);
}

float ReadUV() {
  int uvLevel = averageAnalogRead(UV_OUT);
  int refLevel = averageAnalogRead(UV_3V3);
  float outputVoltage = 3.3 / refLevel * uvLevel;
  float uvIntensity = mapfloat(outputVoltage, 0.99, 2.9, 0.0, 15.0);

  return uvIntensity;
}

float ReadDust() {
  float voMeasured = 0;
  float calcVoltage = 0;
  float dustDensity = 0;

  digitalWrite(DUST_LED_PIN, LOW);
  delayMicroseconds(DUST_SAMPLING_TIME);

  voMeasured = analogRead(DUST_OUT_PIN);

  delayMicroseconds(DUST_DELTA_TIME);
  digitalWrite(DUST_LED_PIN, HIGH);
  delayMicroseconds(DUST_SLEEP_TIME);

  calcVoltage = (float)voMeasured * (5.0 / 1024.0);

  if(calcVoltage >= 0.6)
    dustDensity = 0.17 * calcVoltage - 0.1;
  else
    dustDensity = 0;

  return dustDensity;
}

String ReadTime() {
  bool h12, PM;
  int second = 0, minute = 0, hour = 0, date = 0, month = 0, year = 0;
  //String secondStr="",minuteStr="",hourStr="",dateStr="",monthStr="";

  second = Clock.getSecond();
  minute = Clock.getMinute();
  hour = Clock.getHour(h12, PM);
  date = Clock.getDate();
  month = Clock.getMonth(Century);
  year = Clock.getYear();

  /*if(second<10)
    secondStr=secondStr+"0"+second;
    else
    secondStr+=second;
    if(minute<10)
    minuteStr=minuteStr+"0"+minute;
    else
    minuteStr+=minute;
    if(hour<10)
    hourStr=hourStr+"0"+hour;
    else
    hourStr+=hour;
    if(date<10)
    dateStr=dateStr+"0"+date;
    else
    dateStr+=date;
    if(month<10)
    monthStr=monthStr+"0"+month;
    else
    monthStr+=month;*/

  // %20 表示“空格”，用在 url 中
  // %20 denotes "space" and is used in url
  String time = (String)"20" + year + "/" + month + "/" + date + "%20" + hour + ":" + minute + ":" + second;

  return time;
}

int averageAnalogRead(int pinToRead){
  byte numberOfReadings = 8;
  unsigned int runningValue = 0;

  for (int x = 0 ; x < numberOfReadings ; x++)
    runningValue += analogRead(pinToRead);
  runningValue /= numberOfReadings;

  return (runningValue);
}

float mapfloat(float x, float in_min, float in_max, float out_min, float out_max){
  return (x - in_min) * (out_max - out_min) / (in_max - in_min) + out_min;
}

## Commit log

2018-02-28 add case module
    [case.scad]
2018-12-29 add i2c lcd lib
2018-12-29 replace DHT11 with AM2320 remove lcd
    [WeatherStation.ino]
2018-12-31 Revert "show latest data"
    This reverts commit 78140585938ef6578154760c8cc3cc17b85c05a8.
    [WeatherStation.ino]
2019-01-02 add stl models
    [case.scad, case_bottom.stl, case_top.stl]
2019-01-04 pressure parseInt(value.min)
